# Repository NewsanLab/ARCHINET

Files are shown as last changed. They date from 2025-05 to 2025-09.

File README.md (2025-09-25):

# ARCHINET
Archi Net es una placa de desarrollo diseñada para facilitar la conectividad mediante WiFi, Ethernet y Bluetooth Low Energy (BLE). Cuenta con 4 entradas analógicas y 8 entradas/salidas digitales.

El diseño está pensado para que todas las funciones puedan ser programadas y controladas directamente desde el microcontrolador ARCHI (basado en RP2040), sin necesidad de programar el ESP32 por separado. Este actúa como un coprocesador de comunicaciones, operando mediante comandos enviados en formato Json.

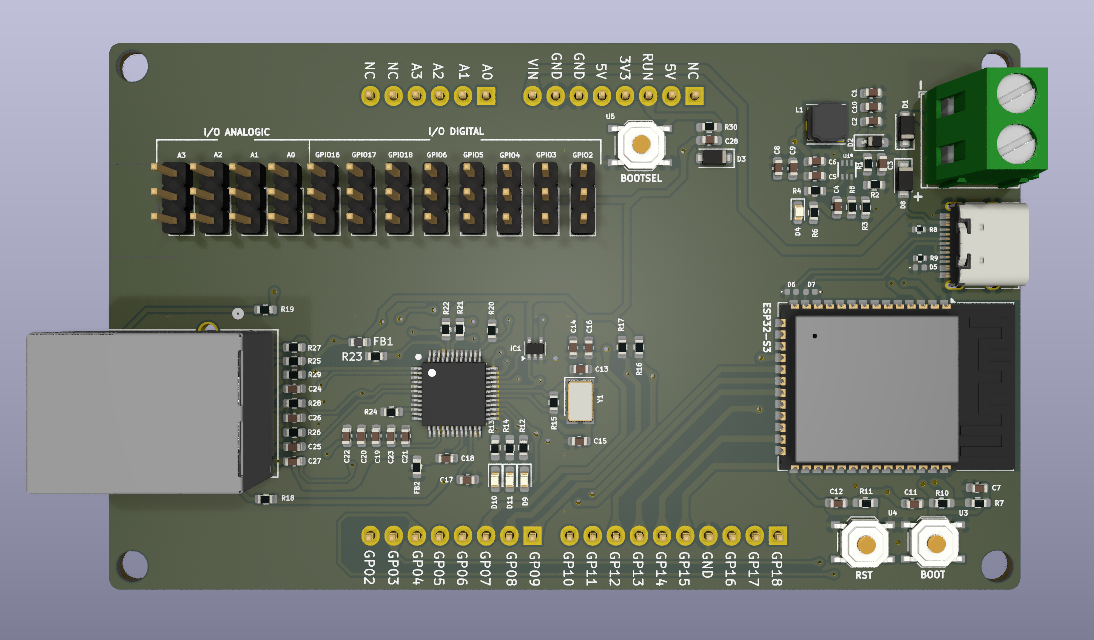
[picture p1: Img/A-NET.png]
Texto alternativo para la imagen


## Especificaciones

* **Voltaje de Entrada del Shield:** 5V a 12V.
* **Conectividad Wi-Fi:** Estándar 802.11 b/g/n (2.4 GHz) con soporte para modos de estación, Punto de Acceso (AP) y Wi-Fi Direct (ESP32-S3).
* **Conectividad Bluetooth:** Bluetooth LE 5.0 (Bluetooth Low Energy).
* **Conectividad Ethernet:** Compatible con 10Base-T/100Base-TX Ethernet (WIZnet W5500).
* **Voltaje de Operación Interno:** Los módulos internos (ESP32-S3 y W5500) operan típicamente a 3.3V, provistos por reguladores a bordo del shield.
* **Pines de Entrada/Salida (I/O):**
    * 4 Entradas/Salidas Analógicas.
    * 8 Entradas/Salidas Digitales.
* **Programación/Depuración:** Incluye un puerto USB JTAG integrado para la programación y depuración directa del ESP32-S3.

## Diagrama en Bloques 

#### El shield ArchiNET se divide en 4 bloques funcionales principales:

* **Fuente de Alimentación:** Este bloque garantiza la alimentación estable a los bloques de conectividad.
* **Archi:** Es el microcontrolador principal que controla la comunicación y funcionalidad de los bloques de conectividad (ESP32 y Ethernet WIZNET W5500).
* **ESP32-S3:** Funciona como un coprocesador dedicado a la conectividad inalámbrica, comunicándose con Archi mediante interfaces como UART o SPI.
* **Ethernet (WIZNET W5500):** Proporciona la conexión de red cableada a través de un puerto RJ45, permitiendo una comunicación Ethernet.

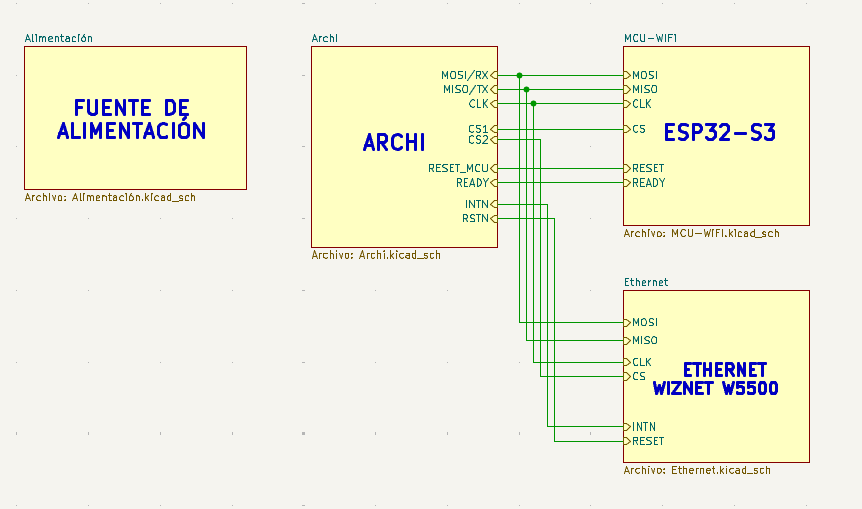
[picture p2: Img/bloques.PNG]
Diagrama en Bloques ArchiNET Diagrama en Bloques de ArchiNET


## Fuente de alimentación
El siguiente diagrama en bloque muestra la distribución de voltaje.

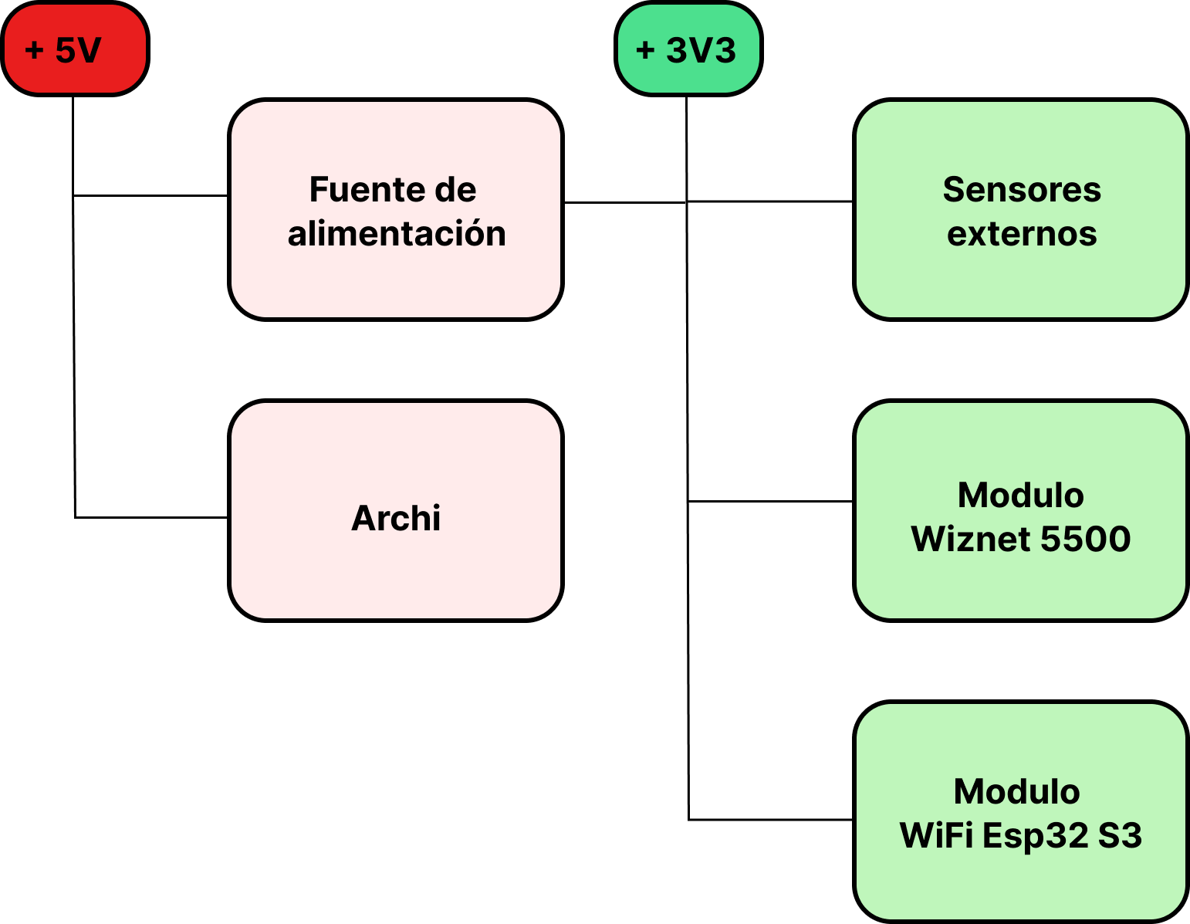
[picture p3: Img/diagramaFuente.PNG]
Fuente ArchiNET Fuente de alimentación


El shield ArchiNet tiene una entrada para una fuente externa de +5V con una capacidad de hasta 2A.

Este voltaje de +5V se utiliza para la alimentación principal de la placa. La placa ArchiNet, a su vez, regula este voltaje para obtener una salida de +3.3V.

Esta salida de +3.3V es la que se utiliza para alimentar los módulos de bajo voltaje, como el Wiznet 5500 , el ESP32S3 y sensores

# 💻 Software

## Conexión a Ethernet

Para realizar una conexión por medio de Ethernet se deben tener cargadas las siguientes librerías en la carpeta `CIRCUITPY/lib`:

- `Adafruit_Bus_Device`
- `Adafruit_Wiznet5K`
- `Adafruit_Connection_Manager`
- `Adafruit_Requests`
- `Adafruit_Ticks`

### ⚙️ Configuración de pines

- **SPI**:
  - `SCK` → `GP10`
  - `MOSI` → `GP11`
  - `MISO` → `GP12`
  - `Chip Select (CS)` → `GP9`

###  Prueba de conexión inicial con ETHERNET

Este script permite comprobar que el dispositivo se conecta correctamente a la red mediante Ethernet.

### ¿Qué hace el script?

1. Configura el bus SPI y el pin CS.
2. Inicializa el módulo Ethernet `WIZNET5K`.
3. Crea una sesión HTTP con `adafruit_requests`.
4. Muestra:
   - Versión del chip
   - Dirección MAC
   - Dirección IP asignada

## Ejemplo: Consulta de IP por Ethernet

<a href="https://github.com/NewsanLab/ARCHINET/blob/main/Software/Example/Ethernet/Ejemplo%201%20Consulta%20IP/01.py" target="_blank" style="text-decoration:none; padding:6px 12px; background-color:#0366d6; color:white; border-radius:6px; font-weight:bold;"> Ver código completo en GitHub</a>

###  Fragmento del código 
```python
import board
import busio
import digitalio
import adafruit_connection_manager
import adafruit_requests
from adafruit_wiznet5k.adafruit_wiznet5k import WIZNET5K

spi = busio.SPI(board.GP10, MOSI=board.GP11, MISO=board.GP12)
cs = digitalio.DigitalInOut(board.GP9)
eth = WIZNET5K(spi, cs)

pool = adafruit_connection_manager.get_radio_socketpool(eth)
ssl_context = adafruit_connection_manager.get_radio_ssl_context(eth)
requests = adafruit_requests.Session(pool, ssl_context)

print("Chip Version:", eth.chip)
print("MAC Address:", [hex(i) for i in eth.mac_address])
print("My IP address is:", eth.pretty_ip(eth.ip_address))

```
## ESP32 como Coprocesador (modo UART)

El ESP32 se utiliza como coprocesador encargado de gestionar la conexión WiFi. La comunicación entre el microcontrolador principal (ej. RP2040, Archi u otros) y el ESP32 se realiza mediante UART o SPI, mediante el envío de **comandos en formato JSON**.

---

###  Modos de operación

- **UART**: Se comunica a través de pines TX/RX, usando comandos y respuestas JSON.
- **SPI**: Alternativamente, se puede implementar una versión basada en SPI (no cubierta en este ejemplo, pero compatible).

---

## Conexión WiFi / BLE vía UART

Este ejemplo muestra cómo controlar el ESP32 como coprocesador para conectarse a una red WiFi/BLE mediante UART.

### Conceptos clave

- Comunicación UART entre el microcontrolador principal y el ESP32.
- El pin `ready` indica cuándo el ESP32 está disponible para recibir comandos.
- Uso de JSON para enviar comandos como `CONNECT`, `SCAN`, `STATUS`, etc.
- Reset físico al ESP32 para asegurar un arranque limpio.

---

### ⚙️ Configuración de pines
- **UART y pines de control**:

  - `UART TX` → `GP12`
  - `UART RX` → `GP13`
  - `Pin ready` → `GP14`
  - `Pin reset` → `GP15`

---

### ¿Qué hace el script?

1. Reinicia el ESP32 con un pulso en el pin `reset`.
2. Espera la señal `ready` del ESP32.
3. Envía el comando `CONNECT` con SSID y contraseña.
4. Recibe las respuestas en formato JSON.
5. Finaliza cuando se recibe `{"end": true}` desde el ESP32.

---

###  Ejemplo: Primera conexión a la red

<a href="https://github.com/NewsanLab/ARCHINET/blob/main/Software/Example/WiFi/Conectar%20a%20WiFi/code.py" target="_blank" style="text-decoration:none; padding:6px 12px; background-color:#0366d6; color:white; border-radius:6px; font-weight:bold;"> Ver código completo en GitHub</a>

### Fragmento del código

```python
esp = ESP32UART(tx_pin=board.GP12, rx_pin=board.GP13, ready_pin=board.GP14)

if esp.esperar_ready(timeout=10):
    esp.solicitar_comando({"cmd": "CONNECT", "ssid": "tu_ssid", "pass": "tu_password"})
    esp.leer_respuesta(timeout=20)
else:
    print("ESP32 no está listo.")

```
---
### Ejemplo: Primera conexión mediante BLE 

Para iniciar comunicación BLE se realiza mediante la misma manera por comandos:

```python
 #Inicia BLE->Con el siguiente comando por defecto tiene el nombre de ARCHINET_BLEXX  
    print("\n--- TEST: CONNECT BLE---")
    esp.solicitar_comando({"cmd": "BLEINIT"})
    esp.leer_respuesta(timeout=20) #respuesta el nombre del dispositivo

    while True:
        esp.solicitar_comando({"cmd": "BLETX","data": "{pcb:archinet, version:v2}"})#tx
        esp.solicitar_comando({"cmd": "BLERX"})
        esp.leer_respuesta(timeout=15) #respuesta del ble rx
        time.sleep(2) 
```
Una vez que tienes la conexión hecha, puedes realizar  una app escritorio/celular para obtener datos. 

### Ejemplo de APP recepción y transmisión 

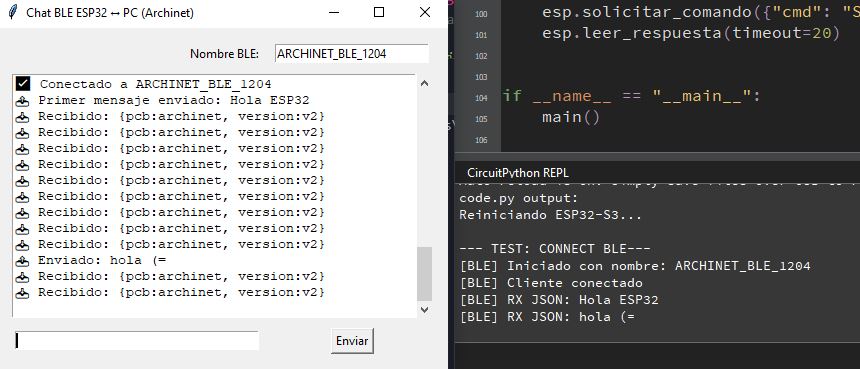
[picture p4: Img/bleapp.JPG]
APP


---

### 📋 Lista de comandos

| Comando | Parámetros | Descripción | 📄 Código de ejemplo |
|---|---|---|---|
| `SCAN` | *(ninguno)* | Escanea y lista redes WiFi disponibles. | [🔗 Ver ejemplo](https://github.com/NewsanLab/ARCHINET/blob/main/Software/Example/WiFi/Escanear/code.py) |
| `CONNECT` | `ssid`, `pass` | Conecta a una red WiFi específica. | [🔗 Ver ejemplo](https://github.com/NewsanLab/ARCHINET/blob/main/Software/Example/WiFi/Conectar%20a%20WiFi/code.py) |
| `DISCONNECT`  | `target` (`"WiFi"` o `"AP"`) | Desconecta de la red o cierra el punto de acceso. | [🔗 Ver ejemplo](https://github.com/NewsanLab/ARCHINET/blob/main/Software/Example/WiFi/Desconectar%20Red/code.py) |
| `AP` | `ssid`, `pass` | Crea un punto de acceso (Access Point). | [🔗 Ver ejemplo](https://github.com/NewsanLab/ARCHINET/blob/main/Software/Example/WiFi/Conectar%20a%20AP/code.py) |
| `PING` | *(ninguno)* | Verifica si el ESP32 está activo y responde con su IP. | [🔗 Ver ejemplo](https://github.com/NewsanLab/ARCHINET/blob/main/Software/Example/WiFi/Informaci%C3%B3n%20de%20conexi%C3%B3n/code.py) |
| `INFO` | *(ninguno)* | Devuelve información del sistema: IP, RSSI y memoria disponible. | [🔗 Ver ejemplo](https://github.com/NewsanLab/ARCHINET/blob/main/Software/Example/WiFi/Informaci%C3%B3n%20de%20conexi%C3%B3n/code.py) |
| `GET` | `url` | Realiza una petición HTTP GET a la URL indicada. | [🔗 Ver ejemplo](https://github.com/NewsanLab/ARCHINET/blob/main/Software/Example/WiFi/Consulta%20GET/code.py) |
| `POST` | `url`, `data` | Envía datos mediante HTTP POST (JSON) a la URL especificada. | [🔗 Ver ejemplo](https://github.com/NewsanLab/ARCHINET/blob/main/Software/Example/WiFi/Consulta%20POST/code.py) |
| `WebServer` | `label`, `data` | Crea o actualiza un endpoint en el servidor embebido del ESP32. | [🔗 Ver ejemplo](https://github.com/NewsanLab/ARCHINET/blob/main/Software/Example/WiFi/WebServer-API-WiFi/code.py) |
| `HTML` | `html` | Inyecta HTML personalizado en el servidor web embebido. | [🔗 Ver ejemplo](https://github.com/NewsanLab/ARCHINET/blob/main/Software/Example/WiFi/A%C3%B1adir%20HTML/codehtml.py) |
| `UART_OFF` | `UART_OFF` | Apaga el UART para utilizar el Ethernet, para volver utilzar reiniciar esp32.| [🔗 Ver ejemplo](https://github.com/NewsanLab/ARCHINET/blob/main/Software/Example/UART_OFF%26ETHERNET/Code.py) |
| `BLEINIT` | *(ninguno o name)* | Inicia BLE por defecto crea el nombre del dispositivo | [🔗 Ver ejemplo](https://github.com/NewsanLab/ARCHINET/blob/main/Software/Example/BLE/code.py)|
| `BLETX` |  `data` | Realiza la transmisión de datos de BLE , se debe mandar los datos en el parametro data en formato json | [🔗 Ver ejemplo](https://github.com/NewsanLab/ARCHINET/blob/main/Software/Example/BLE/code.py)|
| `BLERX` |  *(ninguno)* | Realiza la recepción de datos de BLE  | [🔗 Ver ejemplo](https://github.com/NewsanLab/ARCHINET/blob/main/Software/Example/BLE/code.py)|
| `BLEOFF` | *(ninguno o name)* | Desactiva el BLE | [🔗 Ver ejemplo](https://github.com/NewsanLab/ARCHINET/blob/main/Software/Example/BLE/BLEOFF.py)|

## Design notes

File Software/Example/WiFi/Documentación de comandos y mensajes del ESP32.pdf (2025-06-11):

## Documentación de comandos y mensajes del ESP32

## Item generales

- Tiene un servidor web básico que sirve una página HTML configurable.
- Permite manejar un punto de acceso WiFi (AP).
- Soporta la creación y gestión dinámica de endpoints HTTP con datos JSON.
- Procesa comandos recibidos en formato JSON vía UART o configurable en SPI.

## Comandos soportados

## 1. SCAN

- Descripción: Escanea las redes WiFi disponibles y envía la lista de SSIDs y su intensidad (RSSI) por UART.

Ejemplo JSON:

{ "cmd": "SCAN" }

- Mensajes UART:
- OK: [ESP32] Escaneando redes WiFi...
- Error: [ESP32] No se encontraron redes WiFi.

## 2. CONNECT

- Descripción: Conecta el ESP32 a una red WiFi usando SSID y contraseña.
- Parámetros:
- "ssid": nombre de la red WiFi.
- "pass": contraseña de la red.

- Ejemplo JSON:

{ "cmd": "CONNECT", "ssid": "MiRed", "pass": "12345678" }

Mensajes UART:

- OK: [ESP32] OK|IP: xxx.xxx.xxx.xxx (IP asignada)
- Error: [ESP32] Error al conectar a la red: MiRed
- Error de parámetros: [ESP32] Falta SSID o PASS en CONNECT.

## 3. DISCONNECT

- Descripción: Desconecta el ESP32 de WiFi o apaga el punto de acceso.
- Parámetro:
- "target": "WiFi" (default) o "AP"

Ejemplo JSON:

{ "cmd": "DISCONNECT", "target": "WiFi" }

- Mensajes UART:
- OK WiFi: [ESP32] WiFi desconectado.
- Error WiFi: [ESP32] No está conectado a ninguna red.
- OK AP: [ESP32] AP detenido

### 4. AP

- Descripción: Inicia un punto de acceso WiFi con SSID y contraseña.
- Parámetros:
- "ssid": nombre del AP.

- "pass": contraseña del AP.

Ejemplo JSON:

{ "cmd": "AP", "ssid": "ESP32_AP", "pass": "password" }

- Mensajes UART:
- OK: [ESP32] AP iniciado: ESP32_AP | IP: 192.168.4.1
- Error: [ESP32] Error al iniciar AP
- Error de parámetros: [ESP32] Faltan datos para AP

## 5. WebServer

- Descripción: Actualiza o crea un endpoint HTTP con respuesta JSON.
- Parámetros:
- "label": nombre del endpoint (p. ej. "Temperatura").
- "data": objeto JSON con datos a responder en ese endpoint.

Ejemplo JSON:

{
"cmd": "WebServer",
"label": "Temperatura",
"data": { "dato1": 25 }
}
- Mensajes UART:
- OK: [ESP32] Endpoint /Temperatura actualizado
- Error (sin conexión WiFi o AP): [ESP32] No se puede crear endpoint. No conectado a WiFi ni en modo AP.

- Error formato: [ESP32] Comando WebServer mal formado: falta 'label'

## 6. GET

- Descripción: Realiza una petición HTTP GET a una URL externa y reporta código de respuesta y contenido.
- Parámetros:
- "url": URL completa para la petición.

Ejemplo JSON:

{ "cmd": "GET", "url": "http://example.com/api" }

- Mensajes UART:
- OK: [ESP32] GET http://example.com/api -> Código: 200 +
contenido JSON (en una línea)
- Error: [ESP32] Error en GET -> Código: XXX
- Error no conectado: [ESP32] No conectado a WiFi, no se puede hacer GET.

## 7. HTML

- Descripción: Actualiza la página HTML servida por el WebServer.
- Parámetros:
- "html": string con contenido HTML.

Ejemplo JSON:

{ "cmd": "HTML", "html": "<h1>Nuevo título</h1>" }

- Mensajes UART:
- OK: [ESP32] HTML actualizado
- Error: [ESP32] No se encontró el campo 'html'.
- Error: [ESP32] Campo 'html' vacío.

## Mensajes generales

- Procesando comando recibido:
[ESP32] Procesando comando: <comando JSON recibido>
- Error parseando JSON:
[ESP32] Error al parsear JSON: <mensaje error>
- Error máximo endpoints alcanzado:
[ESP32] No hay espacio para nuevos endpoints

## Notas adicionales

- Para reiniciar el ESP32 se usa una señal en el pin RESET_SIGNAL_PIN que llama a esp_restart() o boton reset.
- La comunicación por UART imprime los mensajes con prefijo [ESP32] para distinguir mensajes del dispositivo.
- El servidor HTTP atiende endpoints dinámicos según los datos cargados con el comando WebServer.
- Los comandos pueden enviarse en texto plano o en formato JSON (el código actual maneja principalmente JSON).

Código de Prueba:

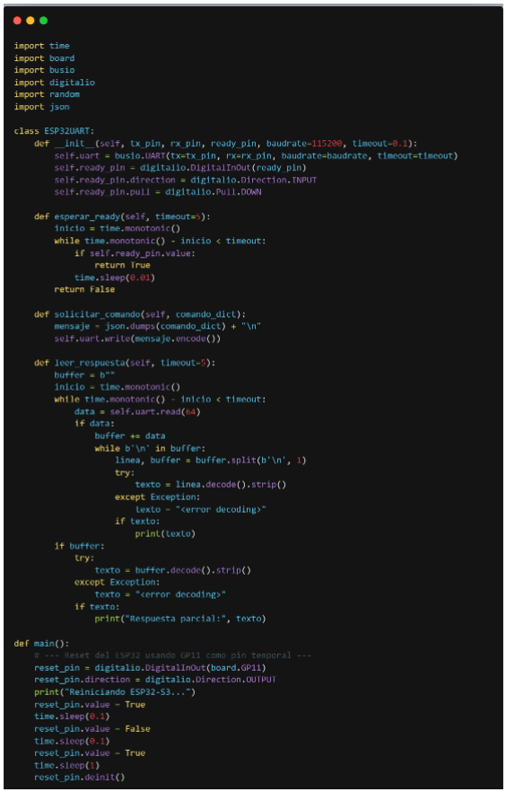
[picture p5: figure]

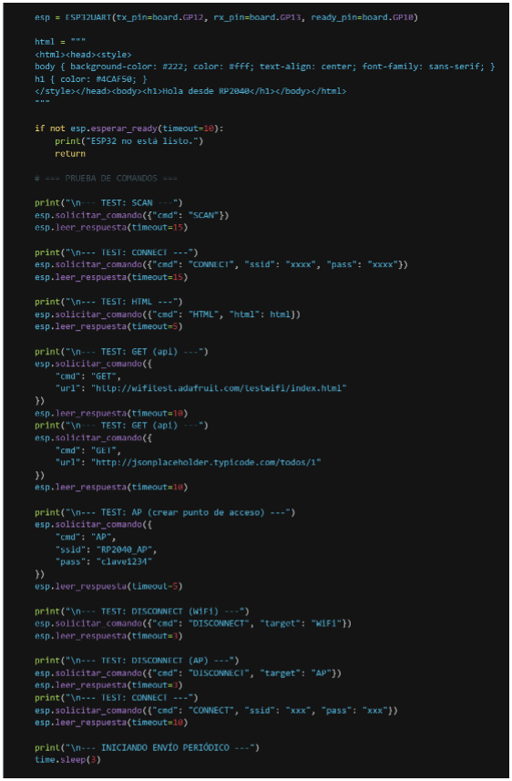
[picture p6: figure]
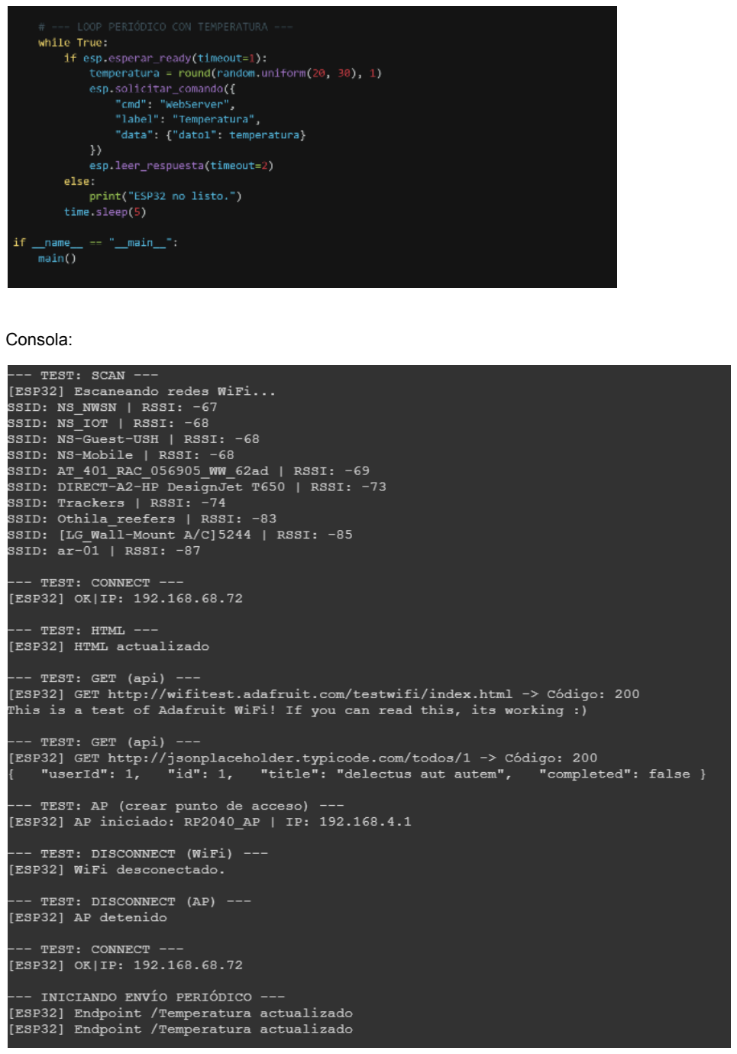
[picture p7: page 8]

Consola:

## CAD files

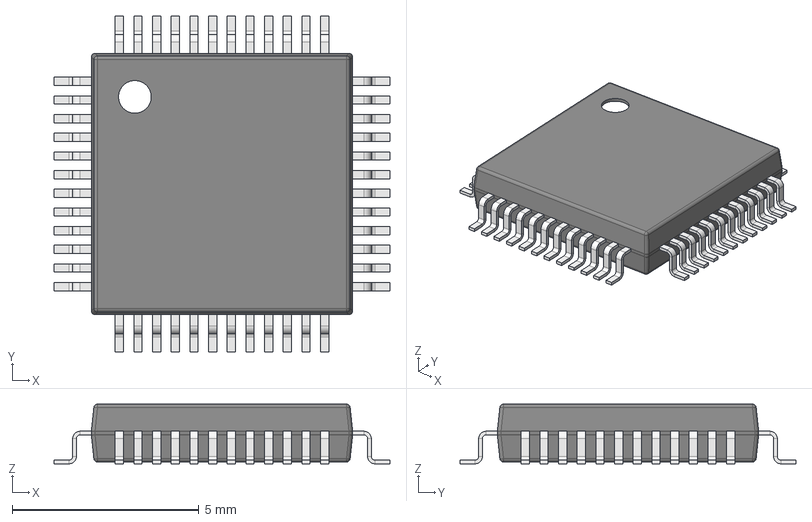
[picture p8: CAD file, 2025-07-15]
Hardware/step/LQFP-48-W5500.step
9.00 x 9.00 x 1.60 mm
Leader x 48

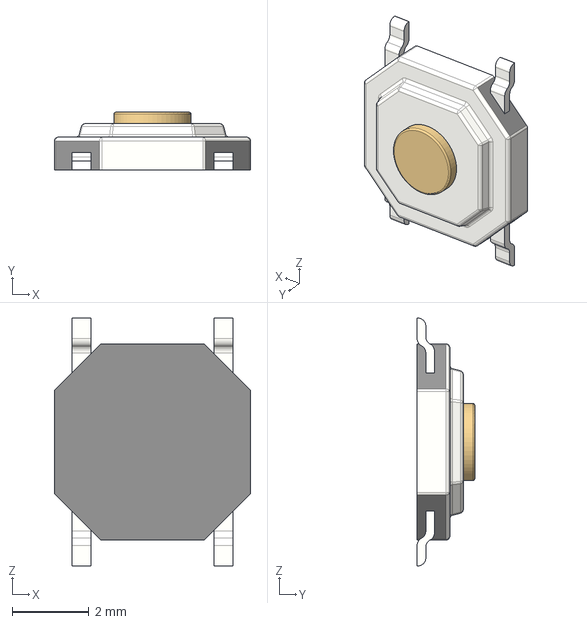
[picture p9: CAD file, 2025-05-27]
Hardware/step/TactileButton(5mm)_SMD.stp
5.10 x 1.50 x 6.45 mm

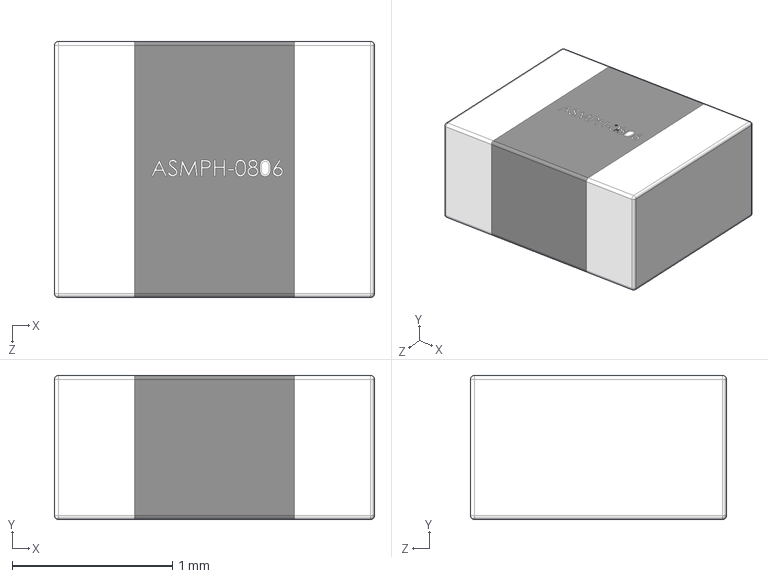
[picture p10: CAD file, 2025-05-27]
Hardware/step/3R3MT.step
2.00 x 0.9 x 1.60 mm

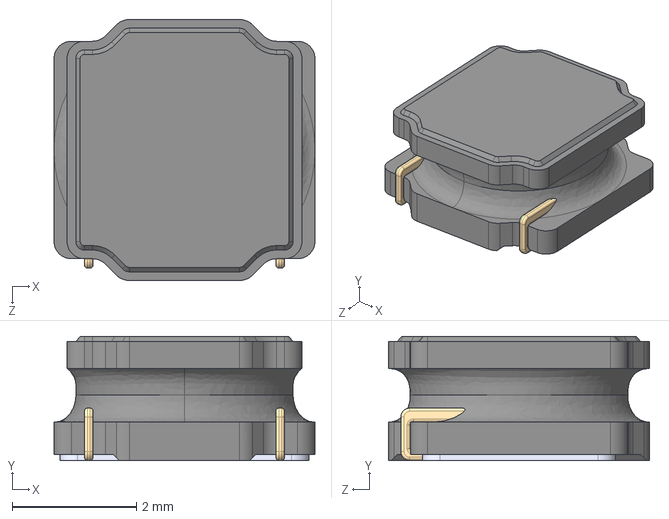
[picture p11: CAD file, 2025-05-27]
Hardware/step/PA4332.222NLT.step
4.20 x 2.00 x 4.20 mm

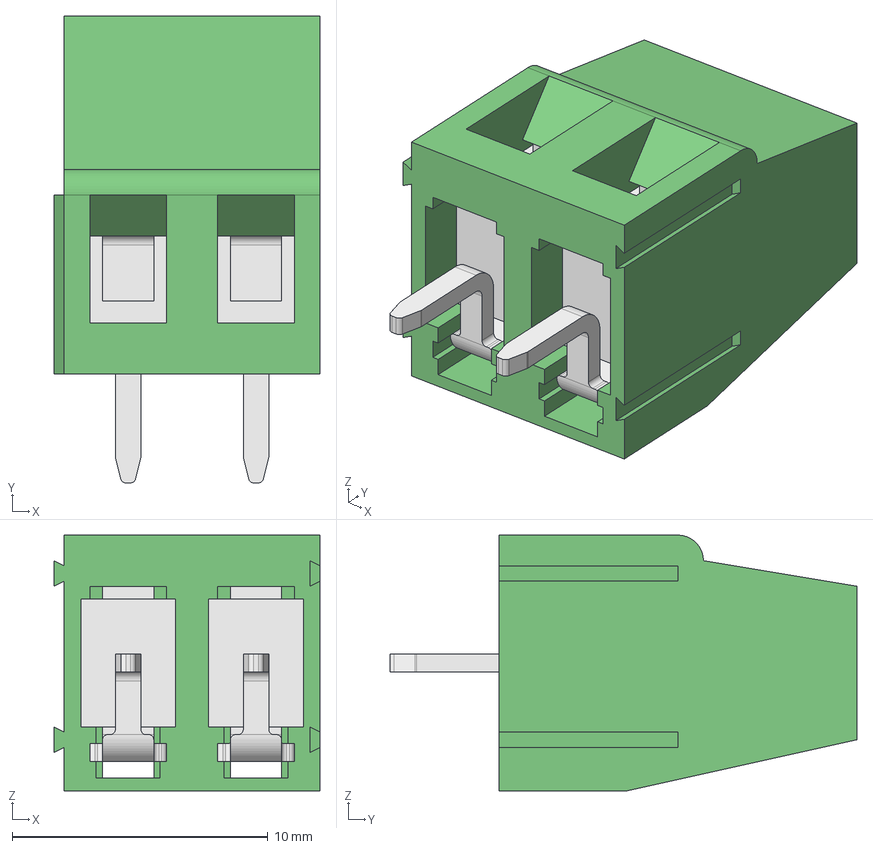
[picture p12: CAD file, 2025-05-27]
Hardware/step/Terminal Block .step
10.4 x 18.3 x 10.0 mm
Base
Cubo interno x 2
Pin x 2
Tornillo x 2

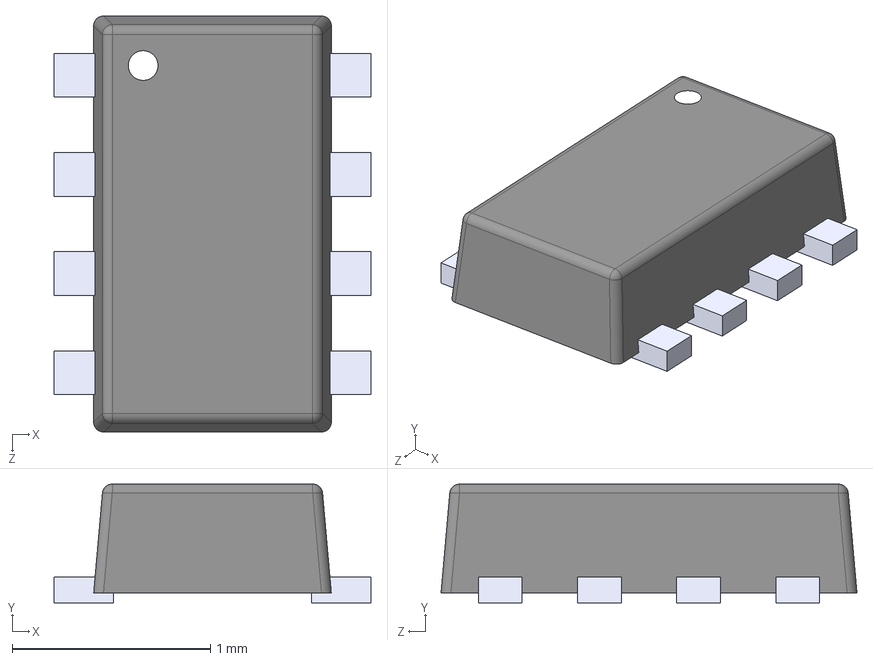
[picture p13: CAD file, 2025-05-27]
Hardware/step/TPS563252DRLR.STEP
1.60 x 0.6 x 2.10 mm

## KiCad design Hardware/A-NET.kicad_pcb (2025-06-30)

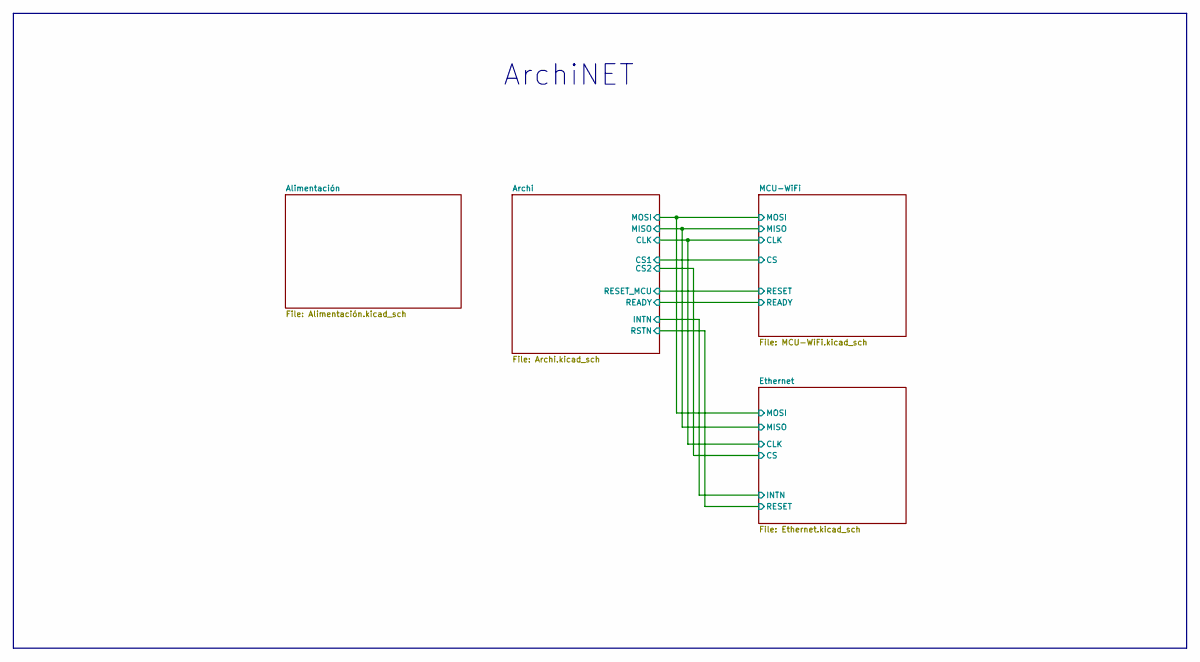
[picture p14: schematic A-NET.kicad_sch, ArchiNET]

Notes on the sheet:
ArchiNET

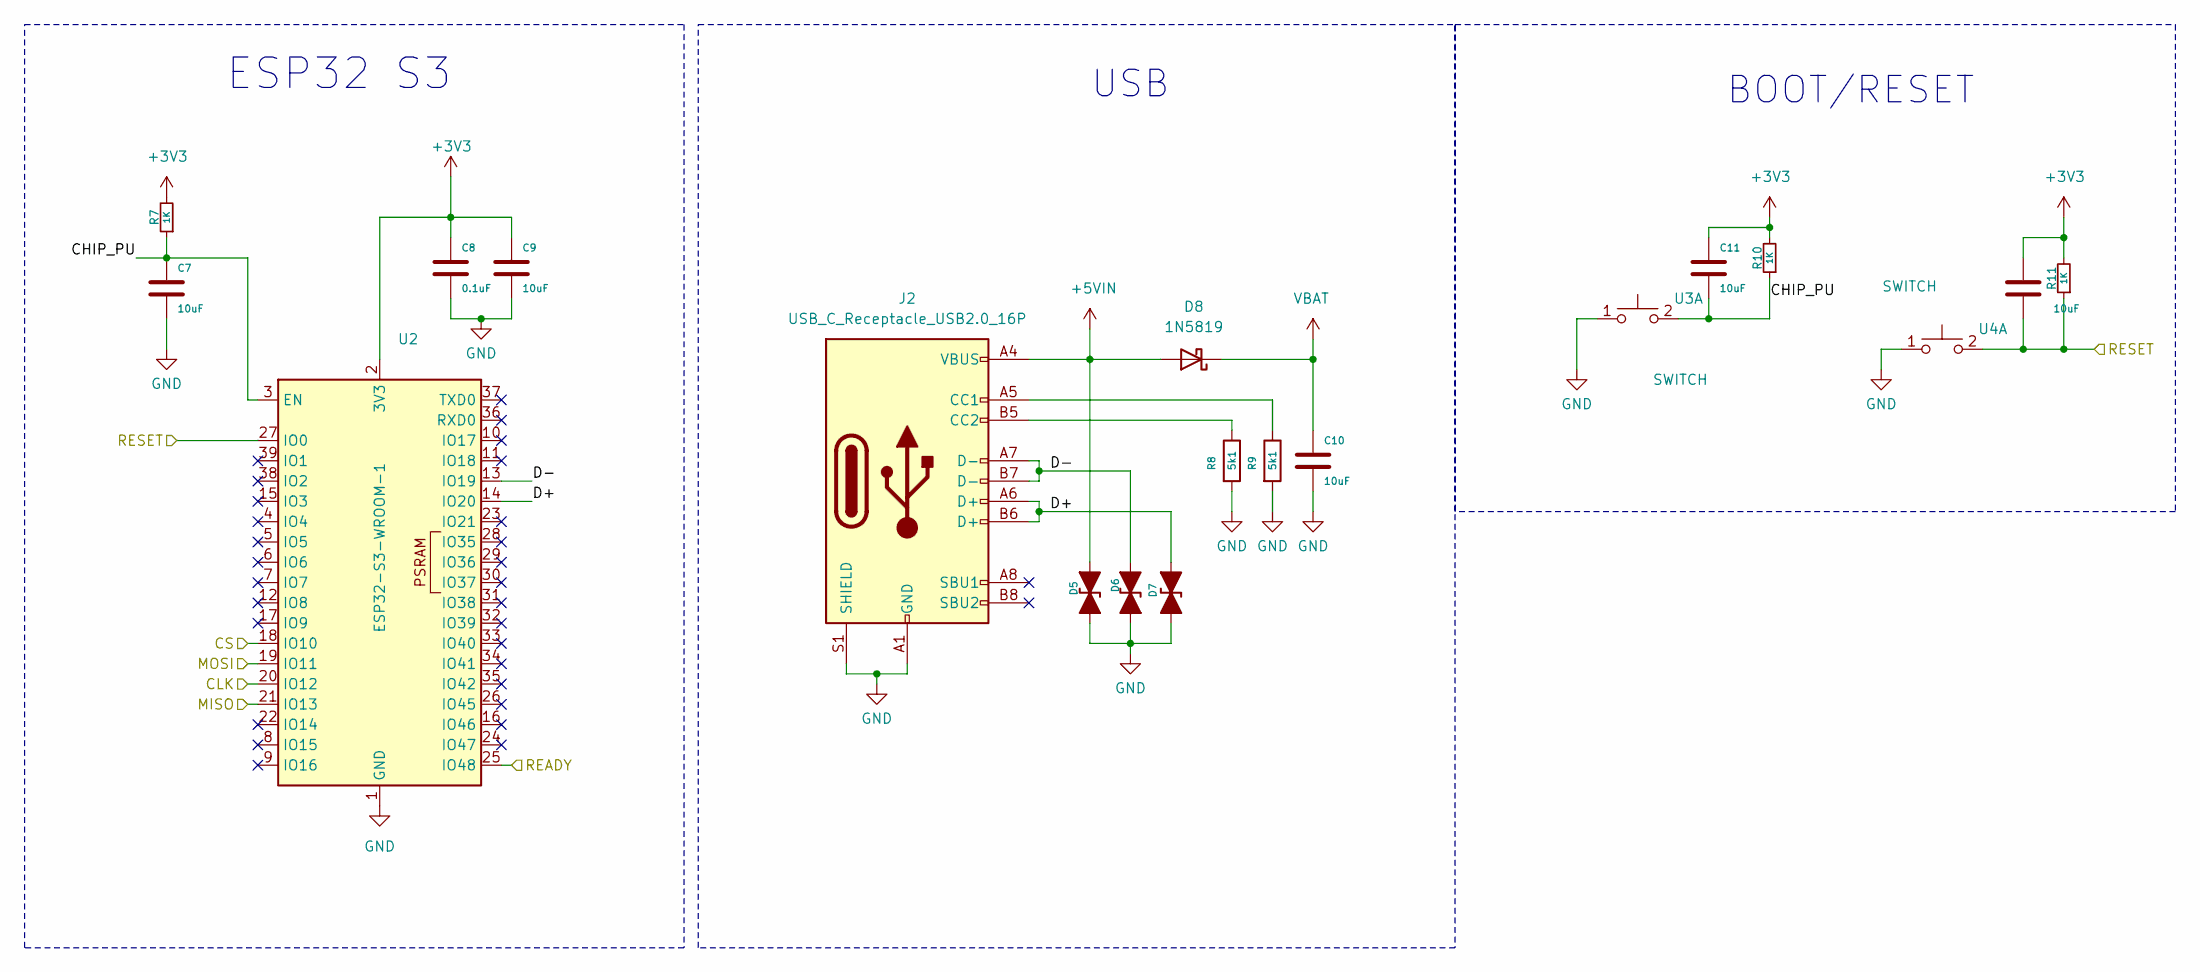
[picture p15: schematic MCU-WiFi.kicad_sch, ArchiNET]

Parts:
C7, C9, C10, C11, C12: 10uF; C_0603_1608Metric; PartNumber CL10X106MO8NRNC
C8: 0.1uF; C_0603_1608Metric; PartNumber CC0603KRX7R7BB104
D5, D6, D7: D_TVS_Filled; D_0402_1005Metric; PartNumber ESD9B5.0ST5G
D8: 1N5819; Nexperia_CFP3_SOD-123W; PartNumber 1N5819WS
J2: USB_C_Receptacle_USB2.0_16P; USB_C_Receptacle_HRO_TYPE-C-31-M-12; PartNumber USB4105-GF-A
R7, R10, R11: 1K; R_0603_1608Metric_Pad0.98x0.95mm_HandSolder; PartNumber RCS06031K00FKEA
R8, R9: 5k1; R_0402_1005Metric; PartNumber ERJ-PA2F5101X
U2: ESP32-S3-WROOM-1; PartNumber ESP32-S3-WROOM-1-N8
U3, U4: SWITCH; SW_Push_1P1T_XKB_TS-1187A; PartNumber PTS526SK15SMTR2 LFS

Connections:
+3V3: C8.1, C9.1, C11.1, C12.1, R7.2, R10.2, R11.2, U2.2 (3V3); also elsewhere on the board
+5VIN: D5.2 (A2), D8.2 (A), J2.A4 (VBUS), J2.A9 (VBUS), J2.B4 (VBUS), J2.B9 (VBUS); also elsewhere on the board
/Archi/CLK: U2.20 (IO12); also elsewhere on the board
/Archi/CS1: U2.18 (IO10); also elsewhere on the board
/Archi/MISO: U2.21 (IO13); also elsewhere on the board
/Archi/MOSI: U2.19 (IO11); also elsewhere on the board
/Archi/READY: U2.25 (IO48); also elsewhere on the board
/Archi/RESET_MCU: C12.2, R11.1, U2.27 (IO0), U4.2 (D); also elsewhere on the board
/MCU-WiFi/CHIP_PU: C7.1, C11.2, R7.1, R10.1, U2.3 (EN), U3.2 (D)
/MCU-WiFi/D+: D7.2 (A2), J2.A6 (D+), J2.B6 (D+), U2.14 (IO20)
/MCU-WiFi/D-: D6.2 (A2), J2.A7 (D-), J2.B7 (D-), U2.13 (IO19)
GND: C7.2, C8.2, C9.2, C10.2, D5.1 (A1), D6.1 (A1), D7.1 (A1), J2.A1 (GND), J2.A12 (GND), J2.B1 (GND), J2.B12 (GND), J2.S1 (SHIELD), R8.2, R9.2, U2.1 (GND), U2.40 (GND), U2.41 (GND), U3.1 (C), U4.1 (C); also elsewhere on the board
unnamed: J2.A5 (CC1), R9.1
unnamed: J2.B5 (CC2), R8.1
VBAT: C10.1, D8.1 (K); also elsewhere on the board

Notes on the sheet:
USB
BOOT/RESET
ESP32 S3

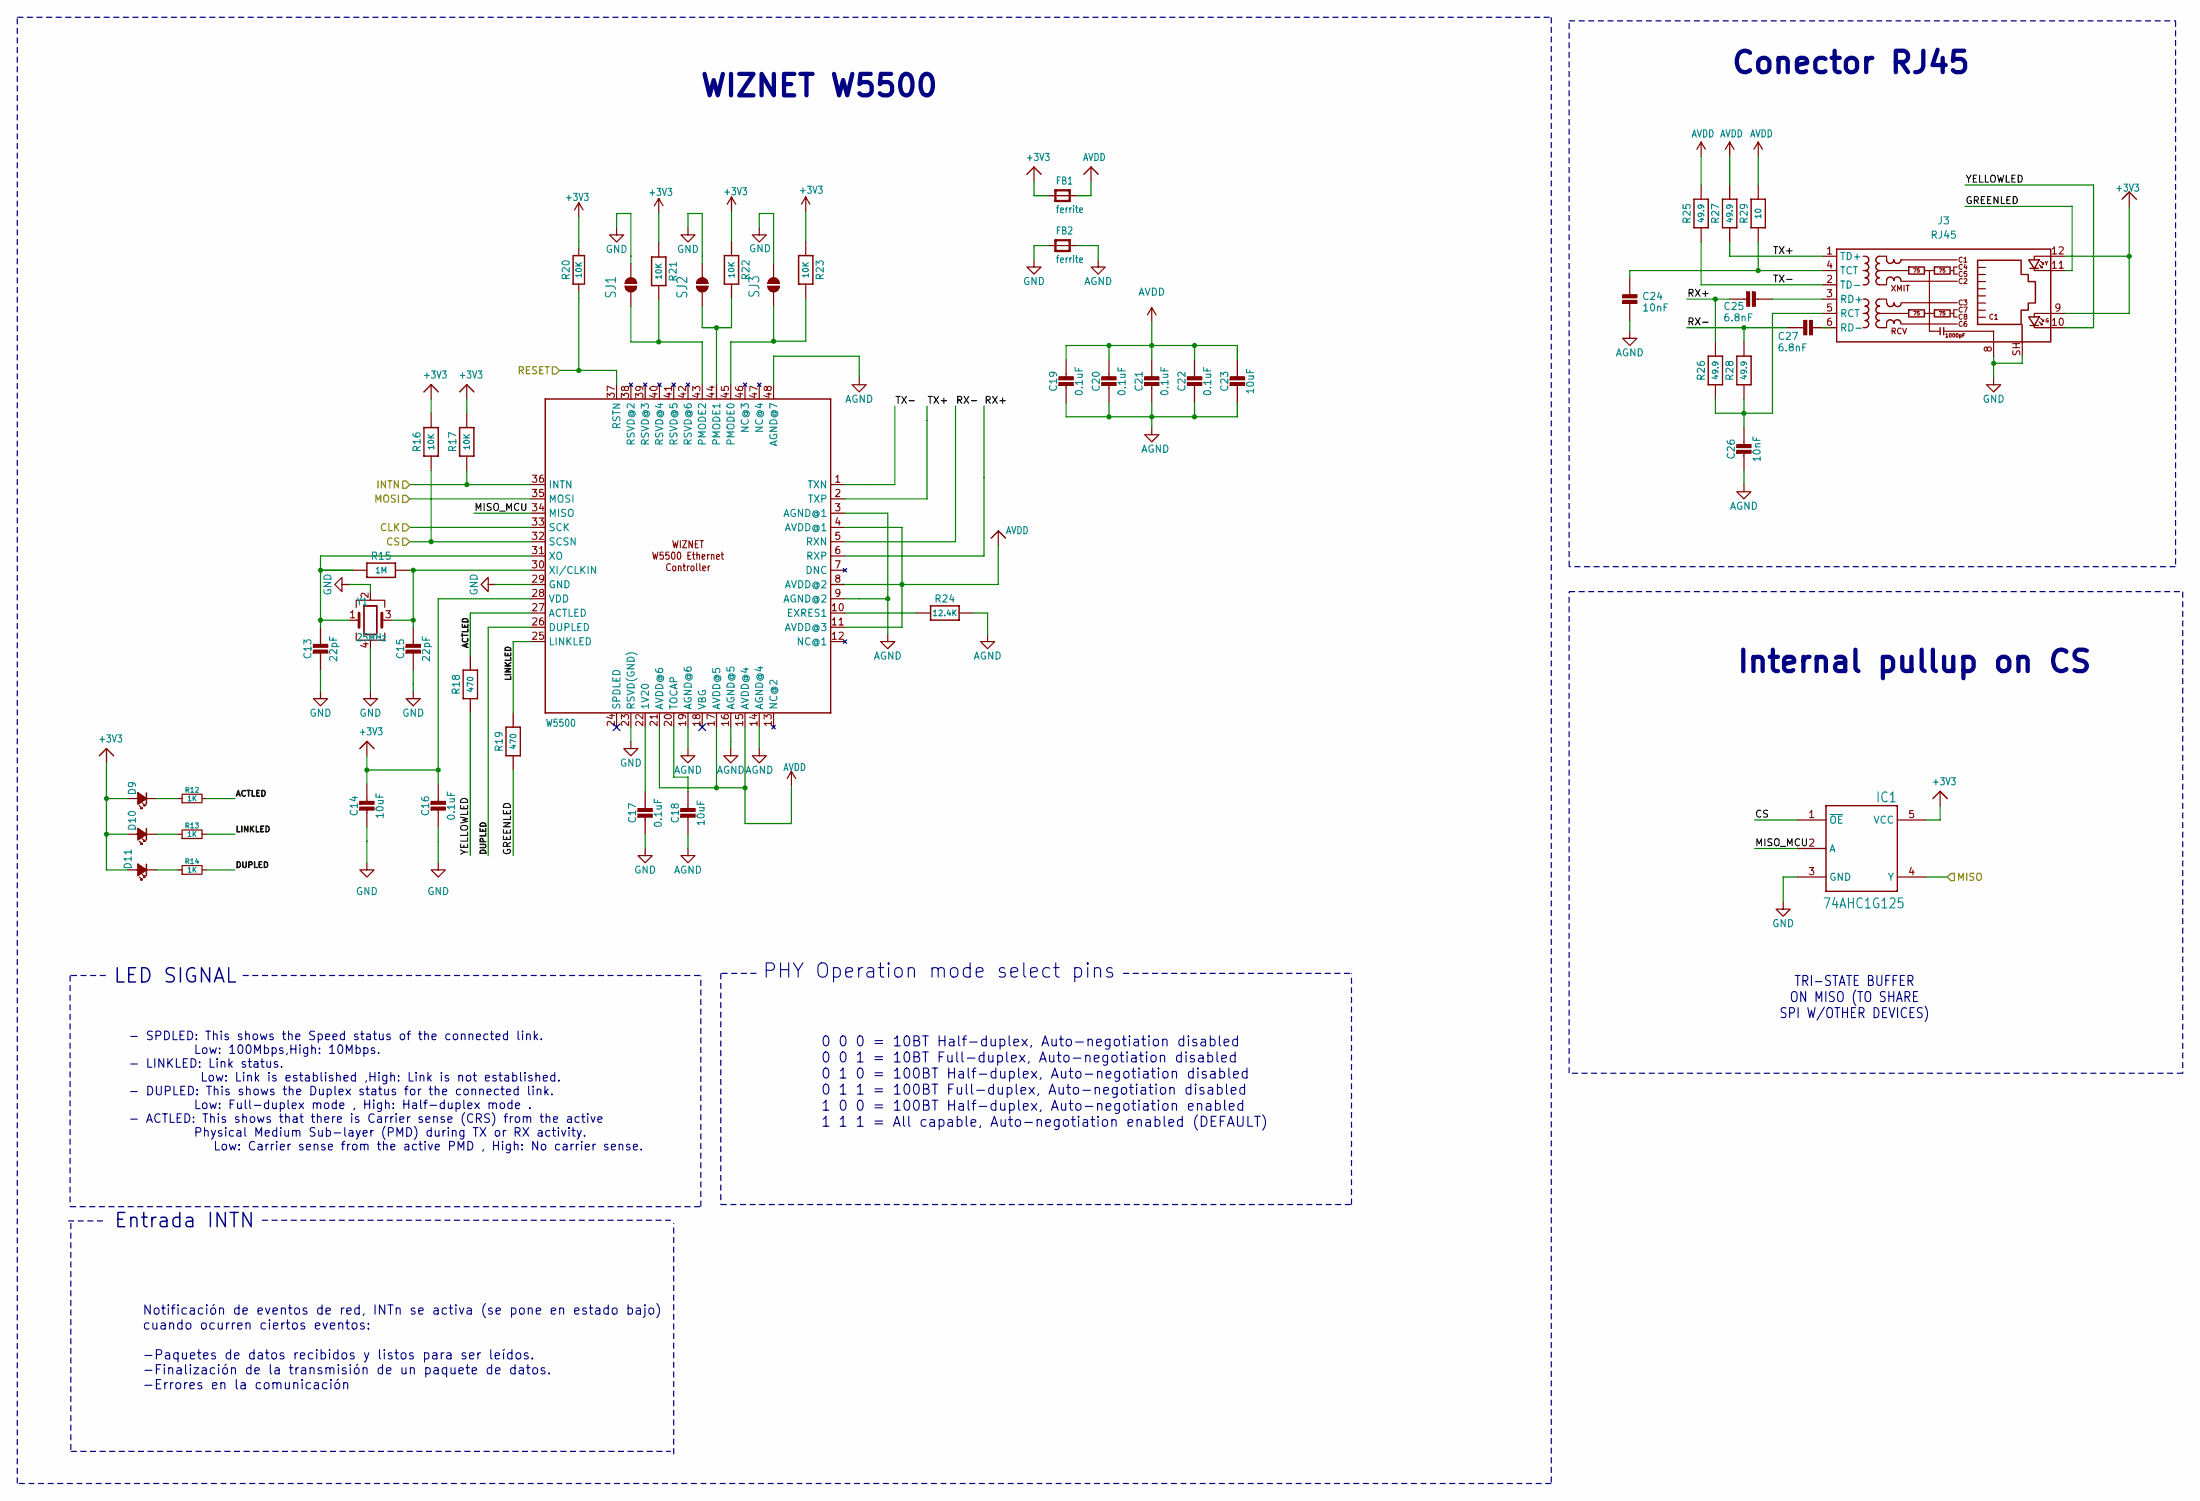
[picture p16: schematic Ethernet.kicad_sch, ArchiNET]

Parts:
C13, C15: 22pF; C_0603_1608Metric; PartNumber C0603C220K4GACTU
C14, C18, C23: 10uF; C_0603_1608Metric; PartNumber CL10X106MO8NRNC
C16, C17, C19, C20, C21, C22: 0.1uF; C_0603_1608Metric; PartNumber CC0603KRX7R7BB104
C24, C26: 10nF; C_0603_1608Metric; PartNumber C0603C103K4RECTU
C25, C27: 6.8nF; C_0603_1608Metric; PartNumber KGM15AR71C682KT
D9, D10, D11: LED_POW; LED_0603_1608Metric_Pad1.05x0.95mm_HandSolder; PartNumber B1931NG--20D001114U1930
FB1: ferrite; L_0603_1608Metric; PartNumber MH1608-121Y
FB2: ferrite; R_0603_1608Metric; PartNumber MH1608-121Y
IC1: 74AHC1G125; SOT-353_SC-70-5; PartNumber SN74AHC1G125DCKR
J3: RJ45; CONN12_ARJM11B1-009-AB-EW2_ABR; PartNumber ARJM11B1-009-AB-EW2
R12, R13, R14: 1K; R_0603_1608Metric_Pad0.98x0.95mm_HandSolder; PartNumber RCS06031K00FKEA
R15: 1M; R_0603_1608Metric; PartNumber RCS06031M00FKEA
R16, R17, R20, R21, R22, R23: 10K; R_0603_1608Metric; PartNumber RCS060310K0JNEA
R18, R19: 470; R_0603_1608Metric; PartNumber CRGP0603F470R
R24: 12.4K; R_0603_1608Metric; PartNumber RCS060312K4FKEA
R25, R26, R27, R28: 49.9; R_0603_1608Metric; PartNumber RCS060349R9FKEA
R29: 10; R_0603_1608Metric; PartNumber RCS060310R0FKEA
SJ1, SJ2, SJ3: SOLDERJUMPERREFLOW_NOPASTE; Jumper
U$1: W5500; PartNumber W5500
Y1: 25MHz; Crystal_SMD_TXC_7M-4Pin_3.2x2.5mm; PartNumber ABM3B-25.000MHZ-22-E-4-H-T

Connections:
+3V3: C14.1, C16.1, D9.2 (A), D10.2 (A), D11.2 (A), FB1.1, IC1.5 (VCC), J3.9, J3.12, R16.2, R17.2, R20.1, R21.1, R22.1, R23.1, U$1.28 (VDD); also elsewhere on the board
/Archi/CLK: U$1.33 (SCK); also elsewhere on the board
/Archi/INTN: R17.1, U$1.36 (INTN); also elsewhere on the board
/Archi/MISO: IC1.4 (Y); also elsewhere on the board
/Archi/MOSI: U$1.35 (MOSI); also elsewhere on the board
/Archi/RSTN: R20.2, U$1.37 (RSTN); also elsewhere on the board
/Ethernet/ACTLED: R12.2, R18.2, U$1.27 (ACTLED)
/Ethernet/CS: IC1.1 (~OE), R16.1, U$1.32 (SCSN); also elsewhere on the board
/Ethernet/DUPLED: R14.2, U$1.26 (DUPLED)
/Ethernet/GREENLED: J3.11, R19.1
/Ethernet/LINKLED: R13.2, R19.2, U$1.25 (LINKLED)
/Ethernet/MISO_MCU: IC1.2 (A), U$1.34 (MISO)
/Ethernet/RX+: C25.2, R26.2, U$1.6 (RXP)
/Ethernet/RX-: C27.2, R28.2, U$1.5 (RXN)
/Ethernet/TX+: J3.1 (TD+), R27.1, U$1.2 (TXP)
/Ethernet/TX-: J3.2 (TD-), R25.1, U$1.1 (TXN)
/Ethernet/YELLOWLED: J3.10, R18.1
AGND: C18.2, C19.2, C20.2, C21.2, C22.2, C23.2, C24.2, C26.2, FB2.2, R24.2, U$1.3 (AGND@1), U$1.9 (AGND@2), U$1.14 (AGND@4), U$1.16 (AGND@5), U$1.19 (AGND@6), U$1.48 (AGND@7)
AVDD: C19.1, C20.1, C21.1, C22.1, C23.1, FB1.2, R25.2, R27.2, R29.2, U$1.4 (AVDD@1), U$1.8 (AVDD@2), U$1.11 (AVDD@3), U$1.15 (AVDD@4), U$1.17 (AVDD@5), U$1.21 (AVDD@6)
GND: C13.2, C14.2, C15.2, C16.2, C17.2, FB2.1, IC1.3 (GND), J3.8, J3.SH, SJ1.2 (B), SJ2.2 (B), SJ3.2 (B), U$1.23 (RSVD(GND)), U$1.29 (GND), Y1.2, Y1.4; also elsewhere on the board
unnamed: D9.1 (K), R12.1
unnamed: D10.1 (K), R13.1
unnamed: D11.1 (K), R14.1
unnamed: C26.1, J3.5 (RCT), R26.1, R28.1
unnamed: C25.1, J3.3 (RD+)
unnamed: C27.1, J3.6 (RD-)
unnamed: C24.1, J3.4 (TCT), R29.1
unnamed: R21.2, SJ1.1 (A), U$1.43 (PMODE2)
unnamed: R22.2, SJ2.1 (A), U$1.44 (PMODE1)
unnamed: R23.2, SJ3.1 (A), U$1.45 (PMODE0)
unnamed: C17.1, U$1.22 (1V20)
unnamed: R24.1, U$1.10 (EXRES1)
unnamed: C18.1, U$1.20 (TOCAP)
unnamed: C15.1, R15.2, U$1.30 (XI/CLKIN), Y1.3
unnamed: C13.1, R15.1, U$1.31 (XO), Y1.1

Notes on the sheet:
PHY Operation mode select pins
Internal pullup on CS
Notificación de eventos de red, INTn se activa (se pone en estado bajo) cuando ocurren ciertos eventos: -Paquetes de datos recibidos y listos para ser leídos. -Finalización de la transmisión de un paquete de datos. -Errores en la comunicación
LED SIGNAL
TRI-STATE BUFFER ON MISO (TO SHARE SPI W/OTHER DEVICES)
0 0 0 = 10BT Half-duplex, Auto-negotiation disabled 0 0 1 = 10BT Full-duplex, Auto-negotiation disabled 0 1 0 = 100BT Half-duplex, Auto-negotiation disabled 0 1 1 = 100BT Full-duplex, Auto-negotiation disabled 1 0 0 = 100BT Half-duplex, Auto-negotiation enabled 1 1 1 = All capable, Auto-negotiation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
WIZNET W5500
- SPDLED: This shows the Speed status of the connected link. Low: 100Mbps,High: 10Mbps. - LINKLED: Link status. Low: Link is established ,High: Link is not established. - DUPLED: This shows the Duplex status for the connected link. Low: Full-duplex mode , High: Half-duplex mode . - ACTLED: This sho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
Entrada INTN
Conector RJ45

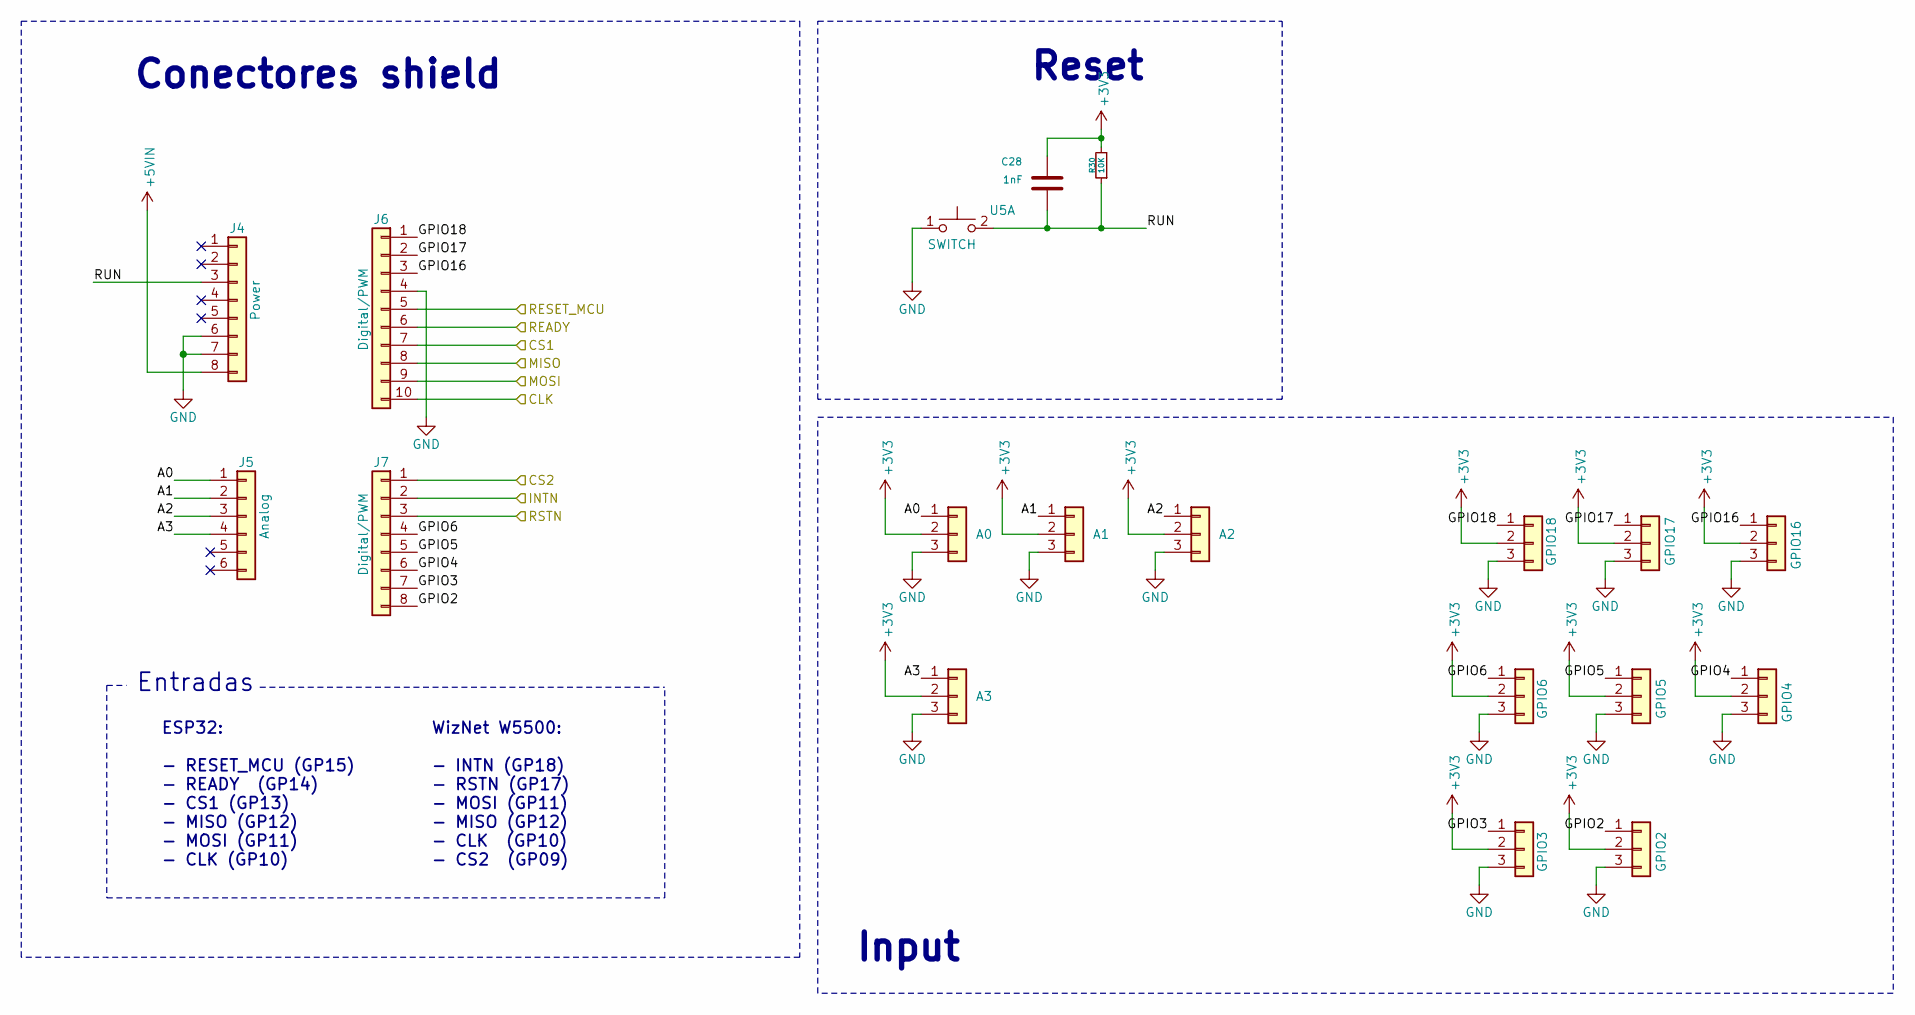
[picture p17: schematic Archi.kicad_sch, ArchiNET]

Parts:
A0, A1, A2, A3: Conn_01x03; PinHeader_1x03_P2.54mm_Vertical
C28: 1nF; C_0603_1608Metric_Pad1.08x0.95mm_HandSolder; PartNumber GRM1885C1H102JA01D
GPIO2, GPIO3, GPIO4, GPIO5, GPIO6, GPIO16, GPIO17, GPIO18: Conn_01x03; PinHeader_1x03_P2.54mm_Vertical
J4: Power; PinHeader_1x08_P2.54mm_Vertical
J5: Analog; PinHeader_1x06_P2.54mm_Vertical
J6: Digital/PWM; PinHeader_1x10_P2.54mm_Vertical
J7: Digital/PWM; PinHeader_1x08_P2.54mm_Vertical
R30: 10K; R_0603_1608Metric_Pad0.98x0.95mm_HandSolder; PartNumber RCS060310K0JNEA
U5: SWITCH; SW_Push_1P1T_XKB_TS-1187A; PartNumber PTS526SK15SMTR2 LFS

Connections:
+3V3: A0.2, A1.2, A2.2, A3.2, C28.1, GPIO2.2, GPIO3.2, GPIO4.2, GPIO5.2, GPIO6.2, GPIO16.2, GPIO17.2, GPIO18.2, R30.2; also elsewhere on the board
+5VIN: J4.8; also elsewhere on the board
/Archi/A0: A0.1, J5.1
/Archi/A1: A1.1, J5.2
/Archi/A2: A2.1, J5.3
/Archi/A3: A3.1, J5.4
/Archi/CLK: J6.10; also elsewhere on the board
/Archi/CS1: J6.7; also elsewhere on the board
/Archi/GPIO2: GPIO2.1, J7.8
/Archi/GPIO3: GPIO3.1, J7.7
/Archi/GPIO4: GPIO4.1, J7.6
/Archi/GPIO5: GPIO5.1, J7.5
/Archi/GPIO6: GPIO6.1, J7.4
/Archi/GPIO16: GPIO16.1, J6.3
/Archi/GPIO17: GPIO17.1, J6.2
/Archi/GPIO18: GPIO18.1, J6.1
/Archi/INTN: J7.2; also elsewhere on the board
/Archi/MISO: J6.8; also elsewhere on the board
/Archi/MOSI: J6.9; also elsewhere on the board
/Archi/READY: J6.6; also elsewhere on the board
/Archi/RESET_MCU: J6.5; also elsewhere on the board
/Archi/RSTN: J7.3; also elsewhere on the board
/Archi/RUN: C28.2, J4.3, R30.1, U5.2 (D)
/Ethernet/CS: J7.1; also elsewhere on the board
GND: A0.3, A1.3, A2.3, A3.3, GPIO2.3, GPIO3.3, GPIO4.3, GPIO5.3, GPIO6.3, GPIO16.3, GPIO17.3, GPIO18.3, J4.6, J4.7, J6.4, U5.1 (C); also elsewhere on the board

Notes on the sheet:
WizNet W5500: - INTN (GP18) - RSTN (GP17) - MOSI (GP11) - MISO (GP12) - CLK (GP10) - CS2 (GP09)
Reset
ESP32: - RESET_MCU (GP15) - READY (GP14) - CS1 (GP13) - MISO (GP12) - MOSI (GP11) - CLK (GP10)
Input
Entradas
Conectores shield

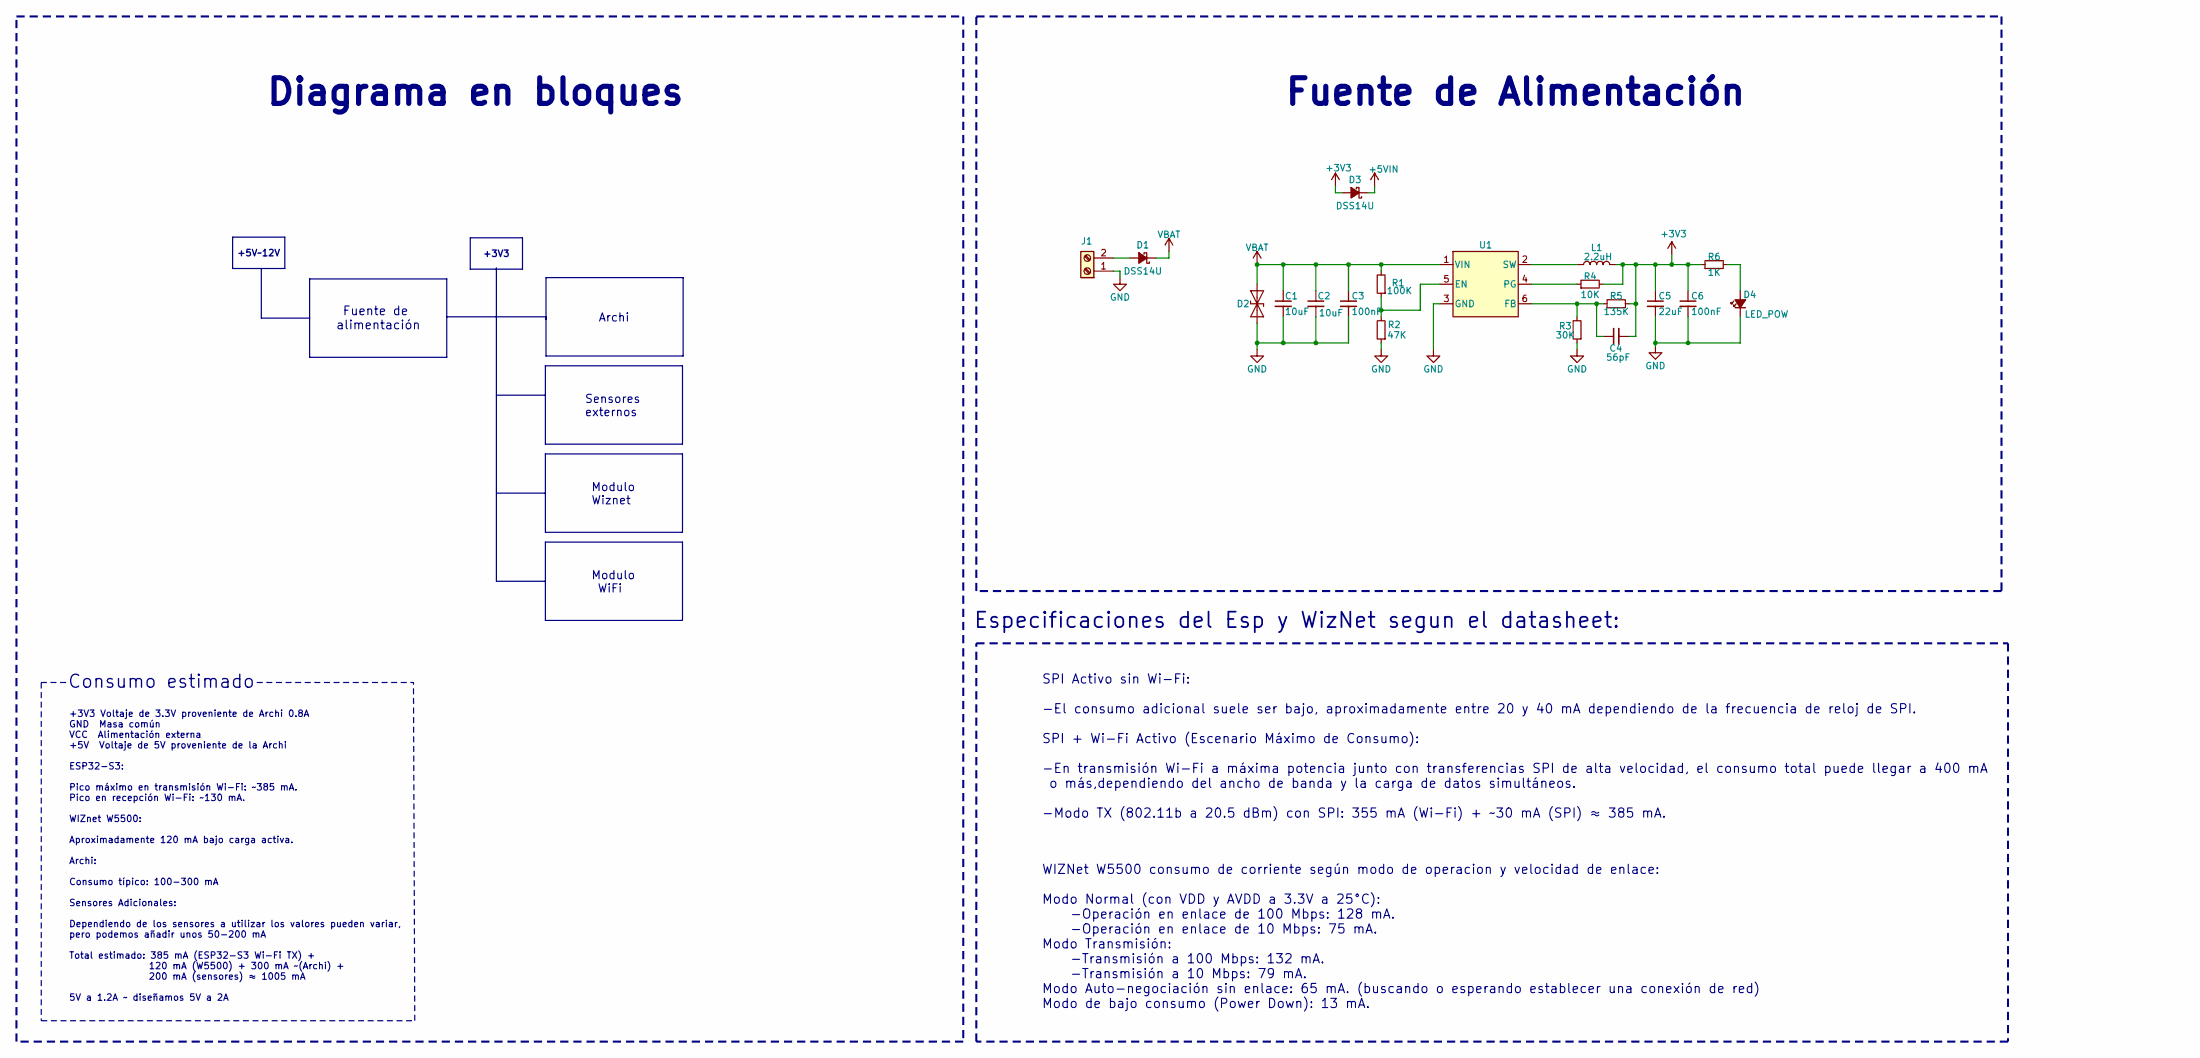
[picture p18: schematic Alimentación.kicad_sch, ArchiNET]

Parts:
C1, C2: 10uF; C_0603_1608Metric; PartNumber CL10X106MO8NRNC
C3, C6: 100nF; C_0603_1608Metric; PartNumber CC0603KRX7R7BB104
C4: 56pF; C_0603_1608Metric; PartNumber C0603C560M3HACTU
C5: 22uF; C_0603_1608Metric; PartNumber GRM188R61A226ME15D
D1, D3: DSS14U; D_SOD-123F; PartNumber DSS14U
D2: SD12C-7; D_SOD-323_HandSoldering; PartNumber SD12C-7
D4: LED_POW; LED_0603_1608Metric; PartNumber B1931NG--20D001114U1930
J1: BAT; TerminalBlock_RND_205-00287_1x02_P5.08mm_Horizontal; PartNumber VI0221520000G
L1: 2.2uH; IND_PA4332.222NLT; PartNumber PA4332.222NLT
R1: 100K; R_0603_1608Metric; PartNumber SR0603FR-7T100KL
R2: 47K; R_0603_1608Metric; PartNumber RCS060332K4FKEA
R3: 30K; R_0603_1608Metric; PartNumber RCS060310K0JNEA
R4: 10K; R_0603_1608Metric; PartNumber RCS060310K0JNEA
R5: 135K; R_0603_1608Metric; PartNumber RT0603BRD07135KL
R6: 1K; R_0603_1608Metric; PartNumber RCS06031K00FKEA
U1: TPS563252DRLR; SOT6_DRL_TEX-L; PartNumber TPS563252DRLR

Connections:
+3V3: C4.2, C5.1, C6.1, D3.2 (A), L1.2, R4.2, R5.2, R6.1; also elsewhere on the board
+5VIN: D3.1 (K); also elsewhere on the board
GND: C1.2, C2.2, C3.2, C5.2, C6.2, D2.2 (A2), D4.1 (K), J1.1, R2.1, R3.1, U1.3 (GND); also elsewhere on the board
unnamed: D1.2 (A), J1.2
unnamed: D4.2 (A), R6.2
unnamed: R1.1, R2.2, U1.5 (EN)
unnamed: C4.1, R3.2, R5.1, U1.6 (FB)
unnamed: R4.1, U1.4 (PG)
unnamed: L1.1, U1.2 (SW)
VBAT: C1.1, C2.1, C3.1, D1.1 (K), D2.1 (A1), R1.2, U1.1 (VIN); also elsewhere on the board

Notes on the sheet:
Modulo Wiznet
SPI Activo sin Wi-Fi: -El consumo adicional suele ser bajo, aproximadamente entre 20 y 40 mA dependiendo de la frecuencia de reloj de SPI. SPI + Wi-Fi Activo (Escenario Máximo de Consumo): -En transmisión Wi-Fi a máxima potencia junto con transferencias SPI de alta velocidad, el consumo total puede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
Consumo estimado
Diagrama en bloques
WIZNet W5500 consumo de corriente según modo de operacion y velocidad de enlace: Modo Normal (con VDD y AVDD a 3.3V a 25°C): -Operación en enlace de 100 Mbps: 128 mA. -Operación en enlace de 10 Mbps: 75 mA. Modo Transmisión: -Transmisión a 100 Mbps: 132 mA. -Transmisión a 10 Mbps: 79 mA. Modo Auto-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
+5V~12V
+3V3
Especificaciones del Esp y WizNet segun el datasheet:
Sensores externos
Archi
Modulo WiFi
Fuente de Alimentación
Fuente de alimentación
+3V3 Voltaje de 3.3V proveniente de Archi 0.8A GND Masa común VCC Alimentación externa +5V Voltaje de 5V proveniente de la Archi ESP32-S3: Pico máximo en transmisión Wi-Fi: ~385 mA. Pico en recepción Wi-Fi: ~130 mA. WIZnet W5500: Aproximadamente 120 mA bajo carga activa. Archi: Consumo típico: 100-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

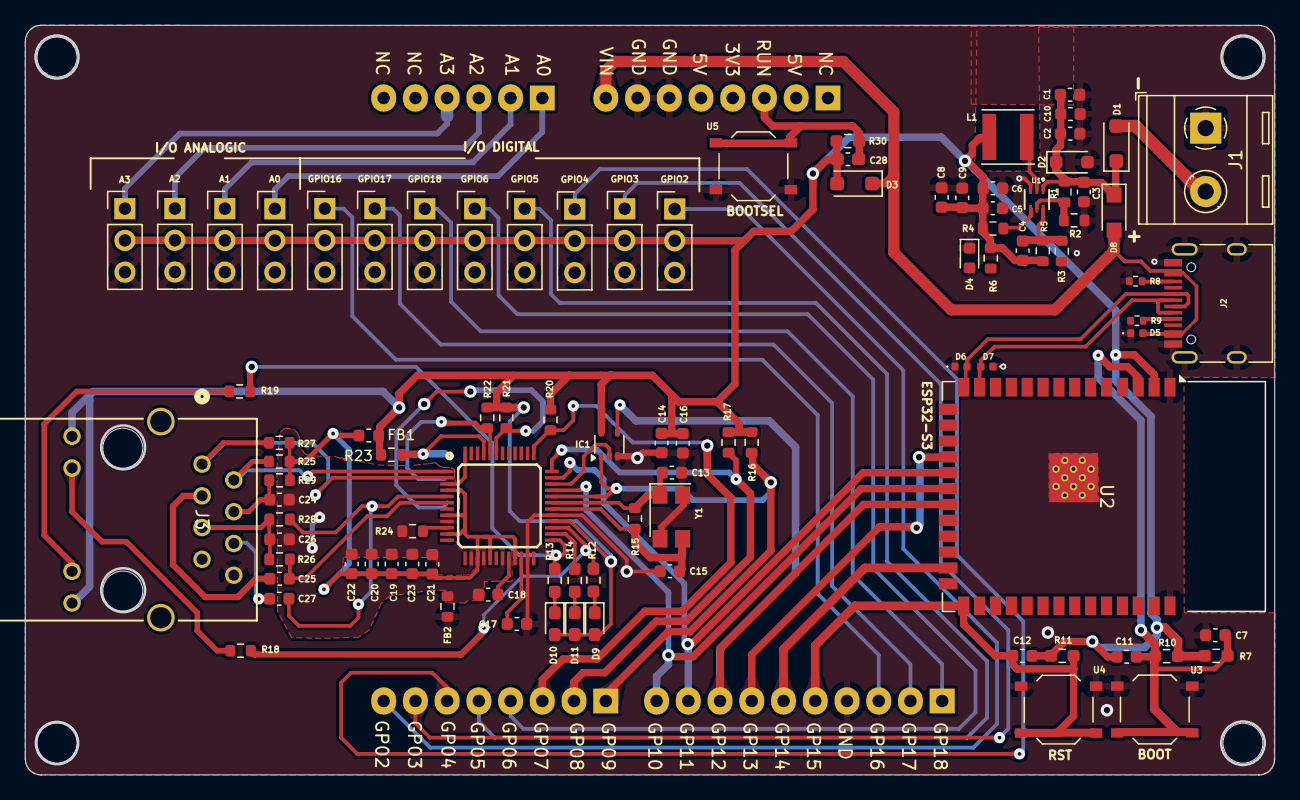
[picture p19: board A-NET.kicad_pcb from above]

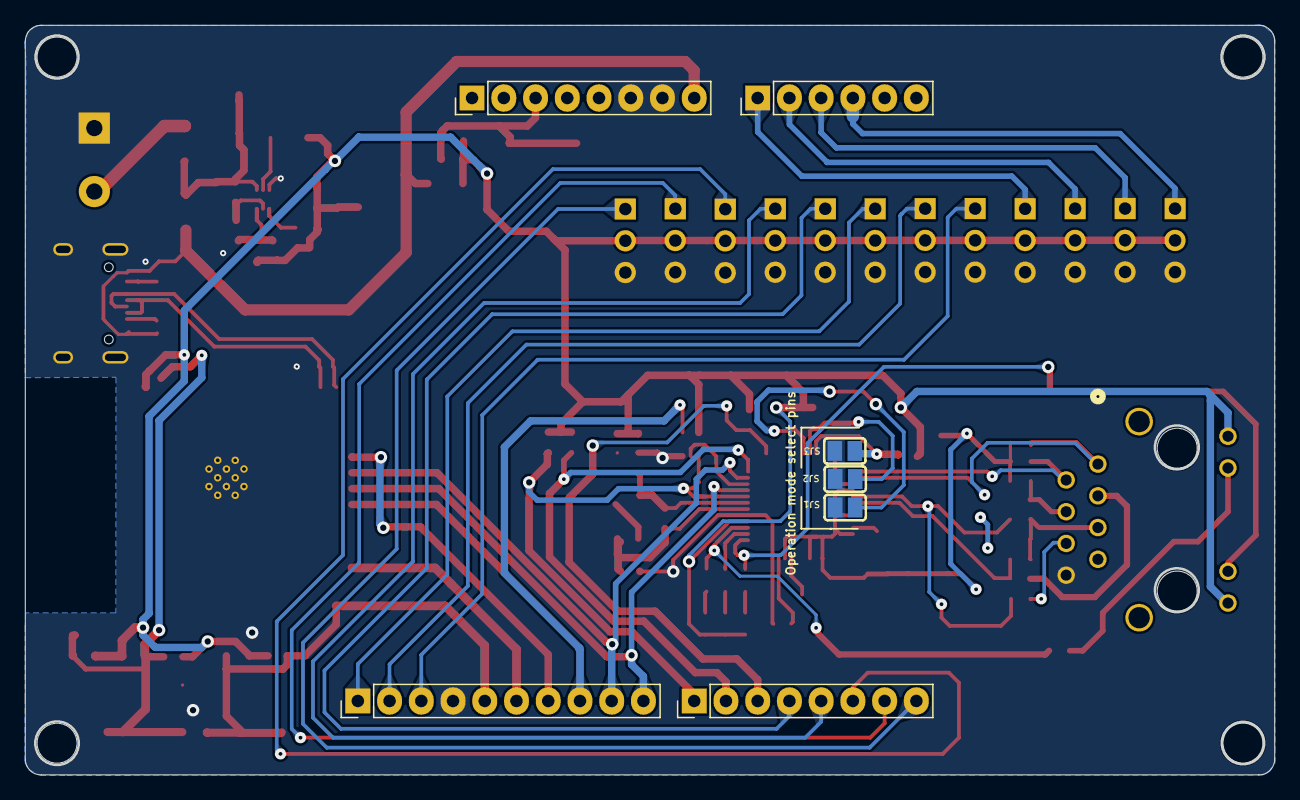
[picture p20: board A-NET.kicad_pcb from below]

Board: 2 copper layers, 100.0 x 60.0 mm, 106 parts (4 on the bottom side), 64 nets.

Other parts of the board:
MH1, MH2, MH3, MH4: MountingHole_3.2mm

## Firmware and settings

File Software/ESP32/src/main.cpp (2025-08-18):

/*
 * Proyecto: Comunicación ESP32 - RP2040
 * Descripción: Este programa gestiona la conexión WiFi y la comunicación UART entre el ESP32 y un RP2040.
 * Autor: A.S
 * Fecha: 8-08-2025
 */
// ======== Librerias ================================================================================== //
#include <Arduino.h>
#include <WiFi.h>
#include <WebServer.h>
#include <HTTPClient.h>
#include <ArduinoJson.h>
#include "globals.h"
#include "functions.h"
#include "commandHandler.h"
const size_t BUF_SIZE = 1024;

//=================================SETUP & LOOP ============================================================
void setup()
{
  Serial.begin(115200); // Debug
  UART1.begin(115200, SERIAL_8N1, RXD_PIN, TXD_PIN);
  pinMode(RESET_SIGNAL_PIN, INPUT);
  attachInterrupt(digitalPinToInterrupt(RESET_SIGNAL_PIN), onResetSignalHigh, RISING);
  sendReadySignal();
  WiFi.mode(WIFI_AP_STA);
  server.onNotFound(handleDynamic);
  server.on("/", handleRoot);
  server.begin();
  delay(100);
  Serial.println("[ESP32] Setup completado.");
}

void loop()
{
  static char buffer[BUF_SIZE];
  static size_t index = 0;

  while (UART1.available() > 0)
  {
    char c = UART1.read();
    if (c == '\n' || c == '\r')
    {
      buffer[index] = '\0';
      String cmd(buffer);
      cmd.trim();
      if (!cmd.isEmpty())
      {
        handleCommand(cmd);
      }
      index = 0;
    }
    else
    {
      if (index < BUF_SIZE - 1)
      {
        buffer[index++] = c;
      }
    }
  }
  server.handleClient();
}

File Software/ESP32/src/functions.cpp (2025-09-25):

#include <Arduino.h>
#include "globals.h"
#include "functions.h"
//========================BLE==============================

class ServerCallbacks : public BLEServerCallbacks
{
    void onConnect(BLEServer *) override
    {
        deviceConnected = true;
        UART1.println("[BLE] Cliente conectado");
    }

    void onDisconnect(BLEServer *) override
    {
        deviceConnected = false;
        UART1.println("[BLE] Cliente desconectado");
    }
};

// ======== Callbacks ======== //
class RxCharacteristicCallbacks : public BLECharacteristicCallbacks
{
    void onWrite(BLECharacteristic *characteristic) override
    {
        if (!bleRxEnabled)
        {
            UART1.println("[BLE] RX está deshabilitado, ignorando datos.");
            return;
        }
        std::string rxValue = characteristic->getValue();
        if (!rxValue.empty())
        {
            UART1.printf("[BLE] RX JSON: %s\n", rxValue.c_str());
            UART1.println("{\"end\": true}"); // Marca de fin
        }
    }
};
void initBLE(const String &deviceName)
{
    // Apagar WiFi antes de activar BLE
    WiFi.disconnect(true);
    WiFi.mode(WIFI_OFF);

    BLEDevice::init(deviceName.c_str());
    pServer = BLEDevice::createServer();
    pServer->setCallbacks(new ServerCallbacks());

    BLEService *pService = pServer->createService(SERVICE_UUID);

    pTxCharacteristic = pService->createCharacteristic(
        COMMANDTX_CHARACTERISTIC_UUID,
        BLECharacteristic::PROPERTY_READ | BLECharacteristic::PROPERTY_NOTIFY);
    pRxCharacteristic = pService->createCharacteristic(
        COMMANDRX_CHARACTERISTIC_UUID,
        BLECharacteristic::PROPERTY_WRITE);

    pRxCharacteristic->setCallbacks(new RxCharacteristicCallbacks());

    pTxCharacteristic->addDescriptor(new BLE2902());
    pRxCharacteristic->addDescriptor(new BLE2902());

    pService->start();

    BLEAdvertising *pAdvertising = BLEDevice::getAdvertising();
    pAdvertising->addServiceUUID(SERVICE_UUID);
    BLEDevice::startAdvertising();

    bleEnabled = true;
    UART1.printf("[BLE] Iniciado con nombre: %s\n", deviceName.c_str());
    UART1.println("{\"end\": true}");
}
void disableBLE()
{
    if (bleEnabled)
    {
        BLEDevice::deinit(true); // Detiene BLE completamente
        bleEnabled = false;
        deviceConnected = false;
        Serial.println("[BLE] BLE apagado.");
        if (uartEnabled)
        {
            UART1.println("[BLE] BLE apagado.");
            UART1.println("{\"end\": true}");
        }
    }
    else
    {
        Serial.println("[BLE] BLE ya estaba apagado.");
    }
}

// ================================= Manejador de interrupción para RESET =================================
void IRAM_ATTR onResetSignalHigh()
{
    esp_restart(); // Reinicia el ESP32
}
// ================================================= Manejadores HTTP ======================================
void handleRoot()
{
    server.send(200, "text/html", htmlPage);
}

void handleHtmlPart(const JsonDocument &doc)
{
    int index = doc["index"] | -1;
    int total = doc["total"] | -1;
    String content = doc["content"] | "";

    if (index < 0 || total < 1 || content.length() == 0)
    {
        UART1.println("[ESP32] Datos HTML_PART inválidos.");
        UART1.println("{\"end\": true}");
        return;
    }

    if (index == 0)
    {
        // Primer fragmento: inicializar buffer y contadores
        htmlBuffer = "";
        expectedTotalParts = total;
        receivedParts = 0;
        Serial.printf("[ESP32] Inicio recepción HTML en %d fragmentos\n", total);
    }

    // Validar orden correcto de fragmentos
    if (index != receivedParts)
    {
        UART1.printf("[ESP32] Fragmento fuera de orden: esperado %d, recibido %d\n", receivedParts, index);
        UART1.println("{\"end\": true}");
        return;
    }

    // Concatenar fragmento al buffer
    htmlBuffer += content;
    receivedParts++;

    // UART1.printf("[ESP32] Recibido fragmento %d/%d\n", index + 1, total);

    // Cuando llegan todos los fragmentos, actualizo la página HTML
    if (receivedParts == expectedTotalParts)
    {
        htmlPage = htmlBuffer;
        // Serial.println("[ESP32] HTML actualizado con todos los fragmentos recibidos.");
        UART1.println("[ESP32] HTML actualizado");
        expectedTotalParts = 0;
        receivedParts = 0;
    }

    UART1.println("{\"end\": true}");
}

// ========================== Funciones para gestionar el Access Point (AP) =============================

// Inicia el Access Point con el SSID y la contraseña proporcionados
void startAccessPoint(const String &ssid, const String &pass)
{

    bool result = WiFi.softAP(ssid.c_str(), pass.c_str());

    if (result)
    {
        IPAddress IP = WiFi.softAPIP();
        UART1.printf("[ESP32] AP iniciado: %s | IP: %s\n", ssid.c_str(), IP.toString().c_str());
        UART1.println("{\"end\": true}");
    }
    else
    {
        UART1.println("[ESP32] Error al iniciar AP");
        UART1.println("{\"end\": true}");
    }
}
// Detiene el Access Point si está activo
void stopAccessPoint()
{
    WiFi.softAPdisconnect(true);
    UART1.println("[ESP32] AP detenido");
    UART1.println("{\"end\": true}");
}

//===============================End POINT=======================================================

// Busca endpoint, devuelve índice o -1 si no existe
int findEndpoint(const String &ep)
{
    for (int i = 0; i < endpointCount; i++)
    {
        if (endpoints[i].endpoint == ep)
            return i;
    }
    return -1;
}

//=========================================Solicitud GET ==========================================

void handleHttpGet(const String &url)
{
    if (WiFi.status() != WL_CONNECTED)
    {
        UART1.println("[ESP32] No conectado a WiFi, no se puede hacer GET.");
        UART1.println("{\"end\": true}"); //

        return;
    }

    HTTPClient http;
    http.begin(url);

    int httpCode = http.GET();
    if (httpCode > 0)
    {
        UART1.printf("[ESP32] GET %s -> Código: %d\n", url.c_str(), httpCode);
        String payload = http.getString(); // Obtener todo el contenido de la respuesta
        payload.trim();                    // Eliminar espacios o saltos al principio o final

        // Imprimir TODO el contenido en UNA SOLA LÍNEA (sin saltos de línea)
        payload.replace("\n", " ");
        payload.replace("\r", " ");

        UART1.print(payload);
        UART1.println(); // Solo un salto de línea final
    }
    else
    {
        UART1.printf("[ESP32] Error en GET -> Código: %d\n", httpCode);
    }

    http.end();
    UART1.println("{\"end\": true}"); //
}
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

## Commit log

2024-11-14 add digikey | add POE
    [A-NET.kicad_sch, Alimentación.kicad_sch, Archi.kicad_sch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]
2025-06-11 #add . ejemplo de software
2025-06-24 #agregado fin de carrera
2025-06-30 .agregado modificaciones pcb
    [A-NET.kicad_pcb, A-NET.kicad_sch, Alimentación.kicad_sch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]
2025-06-30 .add digikey
    [Alimentación.kicad_sch, Archi.kicad_sch, Ethernet.kicad_sch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]
2025-06-30 .add digikey-
    [Archi.kicad_sch]
2025-07-01 .add modificaciónes
    [A-NET.kicad_sch, Archi.kicad_sch, Ethernet.kicad_sch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]
2025-07-15 .añadio comando UART_OFF + ejemplo
2025-08-18 #se actualizo estructura del src esp32
